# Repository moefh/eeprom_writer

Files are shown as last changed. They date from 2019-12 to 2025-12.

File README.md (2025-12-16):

# EEPROM Writer

A simple 28C16 EEPROM writer for Arduino Nano or Uno based on Ben Eater's [EEPROM programmer](https://github.com/beneater/eeprom-programmer).

This project includes:
- An arduino project that accepts commands from the serial USB to read or write the EEPROM
- A command line tool for Linux (might work on Mac?) written in C to read and write data files to the EEPROM

The circuit is heavily based on Ben Eater's [circuit](https://www.youtube.com/watch?v=K88pgWhEb1M) with a few changes to make it more robust when using an Arduino Uno. The main changes are:

- Don't use pin 13 for write enable (which is used by the Arduino during boot to blink the builtin LED). Instead we use the digital output of analog pins A0 to A2 to control the EEPROM chip enable, write enable and output enable pins.
- Add 10k resistors to pull down the shift register inputs do they don't float wildly while the Arduino is starting
- Add 10k resistors to pull up the enable pins of the EEPROM (chip enable, write enable and output enable) to make it more reliable (especially when arduino is starting up). 

## Circuit

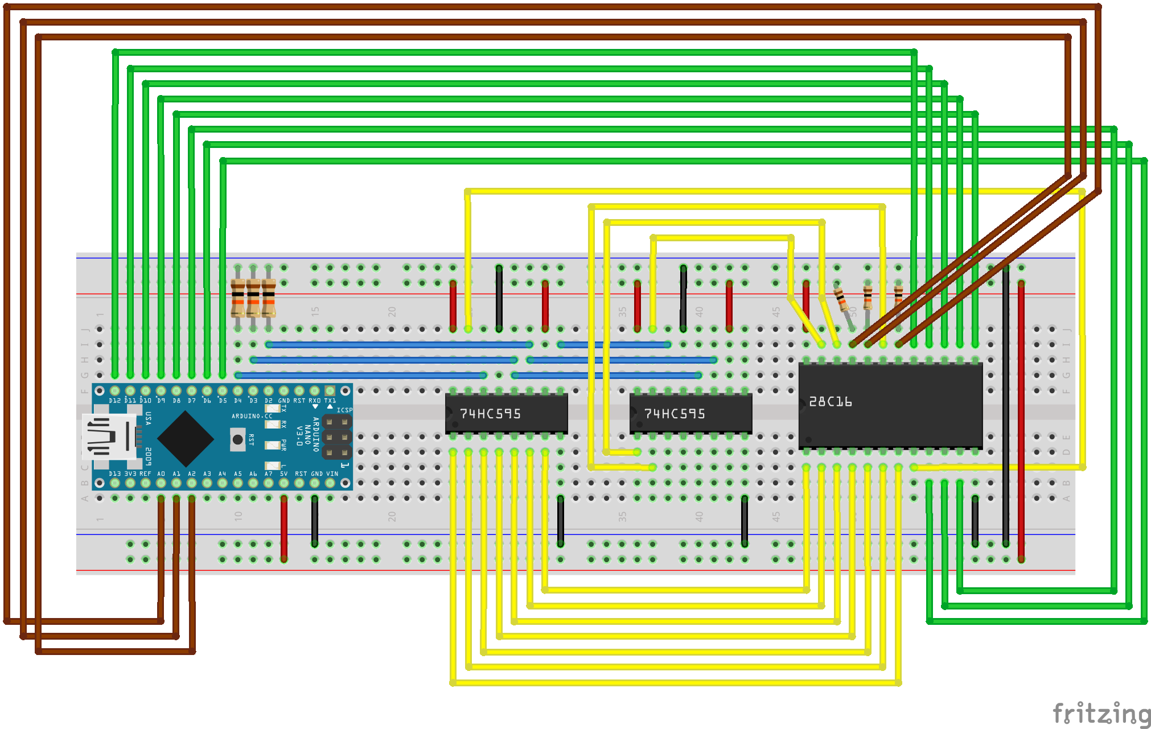
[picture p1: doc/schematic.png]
Schematic


NOTE: the image above shows wrong conections between Arduino pins D2-D4 and the left 74HC595. The correct connections are:

| Arduino | 74HC595 |
| --- | --- |
| D2 | 14 (SER) |
| D3 | 11 (SRCLK) |
| D4 | 12 (RCLK)  |

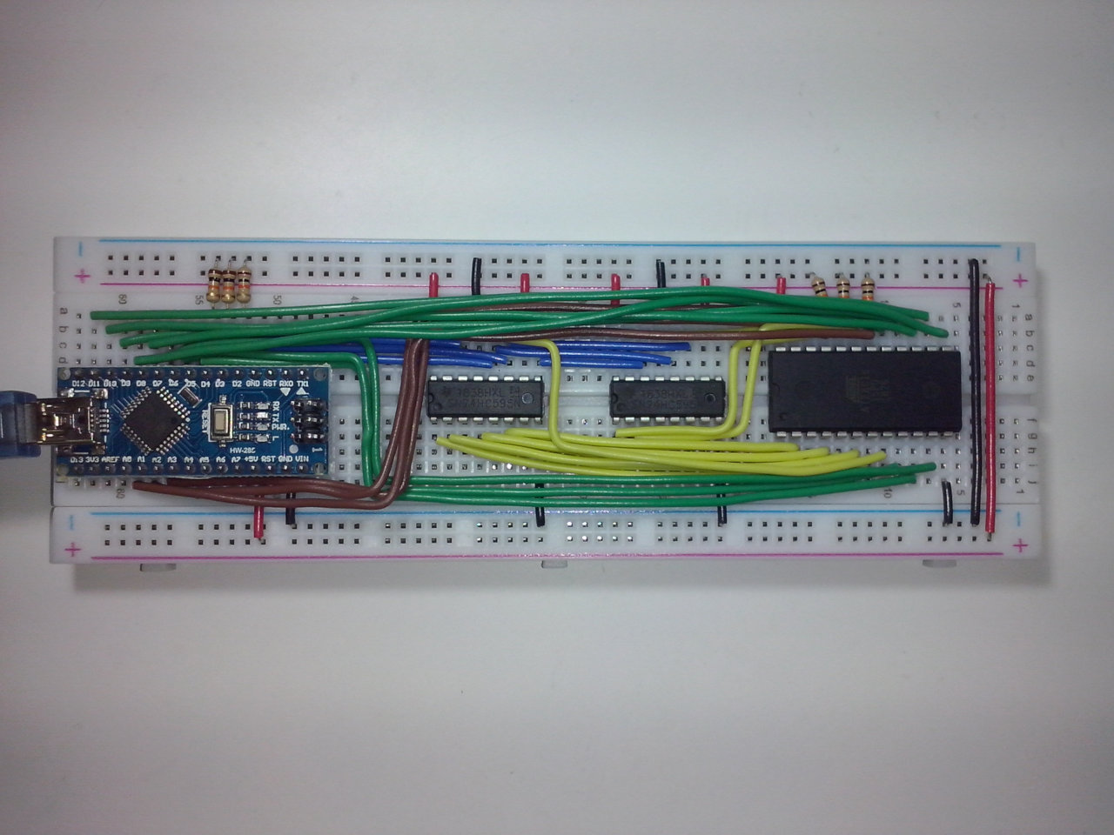
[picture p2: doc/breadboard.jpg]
Breadboard Photo


## Command Line Tool

The command line tool is written in C. To build it, just enter the `cmdline` directory and type `make` (make sure you have the necessary stuff installed, like `build-essential` if using Ubuntu).

The available commands are:

#### Show EEPROM contents

    eeprom dump [ADDRESS [LENGTH]]

Sends the contents of the EEPROM to the standard output formatted as traditional hexdump output. The default `ADDRESS` is `0` and the default `LENGTH` to the end of the EEPROM.  Examples:

    ./eeprom dump              # the whole EEPROM
    ./eeprom dump 0 64         # 64 bytes starting at address 0
    ./eeprom dump 0x200 0x80   # 128 bytes (0x80) starting at address 512 (0x200)

#### Read EEPROM contents to file

    eeprom read FILE [ADDRESS [LENGTH]]

Reads the contents of the EEPROM and writes the data to a file.  The default `ADDRESS` is `0` and the default `LENGTH` is the length of the EEPROM.  Examples:

    ./eeprom read file.bin           # the whole EEPROM
    ./eeprom read file.bin 0 64      # the first 64 bytes
    ./eeprom read file.bin 100 0x20  # 32 bytes (0x20) starting at address 100

#### Write file to EEPROM

    eeprom write FILE [ADDRESS]

Writes the whole contents of a file to the EEPROM.  The default `ADDRESS` is 0.  Examples:

    ./eeprom write file.bin          # writes to start of the EEPROM
    ./eeprom write file.bin 0x400    # writes to the address 1024 (0x400)

## Arduino Project

The Arduino program (found in `arduino/eeprom_writer`) waits for commands from the serial and executes them. The prompt

    *READY

is written to the serial port at the start and after every command is executed successfully. If a command fails, the prompt

    *ERROR: <message>

is written to the serial port.

The available commands are:

#### Dump

    d ADDRESS LENGTH

Reads data from `ADDRESS` to `ADDRESS+LENGTH` and sends it to the serial it in a classic "hexdump" format. Both numbers must be in hexadecimal.

#### Read

    r ADDRESS LENGTH

Reads data from `ADDRESS` to `ADDRESS+LENGTH` and sends it to the serial it in a stream of hex digits with no formatting. Both numbers must be in hexadecimal.

#### Write

    w ADDRESS LENGTH

Reads `LENGTH` pairs of hex digits (each pair representing a byte) from the serial and writes the bytes to the EEPROM starting at address `ADDRESS`. Both numbers must be in hexadecimal. I the data is not sent in 5 seconds, a timeout error is written to the serial and no data is written.

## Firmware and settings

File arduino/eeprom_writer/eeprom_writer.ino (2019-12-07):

// -*- c++ -*-

#define SHIFT_DATA       2
#define SHIFT_CLOCK      3
#define SHIFT_LATCH      4
#define EEPROM_D0        5
#define EEPROM_D7        12

#define EEPROM_CHIP_EN   14
#define EEPROM_OUT_EN    15
#define EEPROM_WR_EN     16

#define EEPROM_WRITE_TIMEOUT_MS 15    // timeout for EEPROM write (ms)
#define SERIAL_READ_TIMEOUT_MS  5000  // timeout for serial read of write buffer (ms)

unsigned char write_buf[512];

char tmp_buf[80];
unsigned int tmp_buf_size;

char cmd_buf[32];
unsigned int cmd_buf_size;
unsigned int cmd_buf_pos;
bool cmd_error_flag;

void setup()
{
  pinMode(LED_BUILTIN, OUTPUT);
  
  eeprom_init();
  
  Serial.begin(115200);
  Serial.println("\n*READY");
}

void loop()
{
  process_serial();
}

// ==============================================================================
// === Serial interface =========================================================
// ==============================================================================

void process_serial()
{
  while (Serial.available() > 0) {
    int b = Serial.read();
    if (b < 0) break;
    cmd_buf[cmd_buf_size++] = b;

    if (cmd_buf_size > 0 && cmd_buf[cmd_buf_size-1] == '\n') {
      cmd_buf_size--;
      process_cmd();
      cmd_buf_size = 0;
    } else if (cmd_buf_size >= (unsigned int) sizeof(cmd_buf)) {
      process_cmd();
      cmd_buf_size = 0;
    }
  }
}

void process_cmd()
{
  if (cmd_buf_size == 0) {
    return;
  }

  cmd_error_flag = false;
  cmd_buf_pos = 1;
  switch (cmd_buf[0]) {
  case 'r': process_read_cmd();    break;
  case 'w': process_write_cmd();   break;
  case 'd': process_dump_cmd();    break;
  default:  process_invalid_cmd(); break;
  }

  if (! cmd_error_flag) {
    Serial.println("\n*READY");
  }
}

void cmd_error(const char *msg)
{
  Serial.print("*ERROR: ");
  Serial.println(msg);
  cmd_error_flag = true;
}

int hex_to_nibble(char ch)
{
  if (ch >= '0' && ch <= '9') return ch - '0';
  if (ch >= 'a' && ch <= 'f') return ch - 'a' + 10;
  if (ch >= 'A' && ch <= 'F') return ch - 'A' + 10;
  return -1;
}

char nibble_to_hex(unsigned int nibble)
{
  if (nibble < 10) {
    return nibble + '0';
  }
  return nibble - 10 + 'a';
}

void write_char(char c)
{
  tmp_buf[tmp_buf_size++] = c;
}

void write_hex_u8(byte b)
{
  tmp_buf[tmp_buf_size++] = nibble_to_hex(b >> 4);
  tmp_buf[tmp_buf_size++] = nibble_to_hex(b & 0x0f);
}

void write_hex_u16(unsigned int b)
{
  tmp_buf[tmp_buf_size++] = nibble_to_hex((b >> 12) & 0x0f);
  tmp_buf[tmp_buf_size++] = nibble_to_hex((b >>  8) & 0x0f);
  tmp_buf[tmp_buf_size++] = nibble_to_hex((b >>  4) & 0x0f);
  tmp_buf[tmp_buf_size++] = nibble_to_hex((b >>  0) & 0x0f);
}

unsigned int read_hex()
{
  while (cmd_buf_pos < cmd_buf_size && cmd_buf[cmd_buf_pos] == ' ') {
    cmd_buf_pos++;
  }
  unsigned int start_pos = cmd_buf_pos;

  unsigned int num = 0;
  while (cmd_buf_pos < cmd_buf_size) {
    int nibble = hex_to_nibble(cmd_buf[cmd_buf_pos]);
    if (nibble < 0) {
      break;
    }
    num = (num << 4) | nibble;
    cmd_buf_pos++;
  }

  if (start_pos == cmd_buf_pos) {
    cmd_error("expected number");
  }
  return num;
}

// --- INVALID
void process_invalid_cmd()
{
  tmp_buf_size = 0;
  write_hex_u8(cmd_buf[0]);
  Serial.print("invalid command byte: ");
  Serial.println(tmp_buf);
  cmd_error("invalid command");
}

// --- READ
void process_read_cmd()
{
  unsigned int addr = read_hex();
  if (cmd_error_flag) return;
  unsigned int len = read_hex();
  if (cmd_error_flag) return;

  tmp_buf_size = 0;
  while (len-- > 0) {
    if (tmp_buf_size+2 >= (unsigned int) sizeof(tmp_buf)) {
      write_char('\0');
      Serial.println(tmp_buf);
      tmp_buf_size = 0;
    }
    byte b = read_eeprom_byte(addr++);
    write_hex_u8(b);
  }
  if (tmp_buf_size > 0) {
    write_char('\0');
    Serial.println(tmp_buf);
  }
}

// --- DUMP
void process_dump_cmd()
{
  unsigned int addr = read_hex();
  if (cmd_error_flag) return;
  unsigned int len = read_hex();
  if (cmd_error_flag) return;

  unsigned int end = addr + len;
  while (addr != end) {
    unsigned int line_len = end - addr;
    if (line_len > 16) line_len = 16;
    for (unsigned int i = 0; i < line_len; i++) {
      cmd_buf[i] = read_eeprom_byte(addr+i);
    }
    dump_line(cmd_buf, line_len, addr);
    addr += line_len;
  }
}

void dump_line(char *d, unsigned int len, unsigned int addr)
{
  tmp_buf_size = 0;
  
  write_hex_u16(addr);
  write_char(':');
  write_char(' ');
  for (unsigned int i = 0; i < len; i++) {
    write_char(' ');
    write_hex_u8(d[i]);
  }
  for (unsigned int i = len; i < 16; i++) {
    write_char(' ');
    write_char(' ');
    write_char(' ');
  }
  write_char(' ');
  write_char(' ');
  for (unsigned int i = 0; i < len; i++) {
    write_char((d[i] >= 0x20 && d[i] < 0x7f) ? d[i] : '.');
  }
  write_char('\0');
  Serial.println(tmp_buf);
}

// --- WRITE
void process_write_cmd()
{
  unsigned int addr = read_hex();
  if (cmd_error_flag) return;
  unsigned int len = read_hex();
  if (cmd_error_flag) return;

  if (len == 0 || len > (unsigned int) sizeof(write_buf)) {
    cmd_error("invalid length");
    Serial.print("len: ");
    Serial.println(len);
    return;
  }
  
  // read data from serial
  unsigned int write_buf_len = 0;
  unsigned long start_time = millis();
  unsigned long timeout_time = start_time + SERIAL_READ_TIMEOUT_MS;
  int high_nibble = -1;
  while (write_buf_len < len) {
    if (millis() > timeout_time) {
      cmd_error("read timeout");
      return;
    }

    while (Serial.available() > 0 && write_buf_len < len) {
      int c = Serial.read();
      if (c >= 0) {
        int nibble = hex_to_nibble(c);
        if (nibble < 0) {
          cmd_error("invalid data");
          return;
        }
        if (high_nibble < 0) {
          high_nibble = nibble << 4;
        } else {
          write_buf[write_buf_len++] = high_nibble | nibble;
          high_nibble = -1;
        }
      }
    }
    if (write_buf_len < len) {
      delay(1);
    }
  }

  // write data to EEPROM
  digitalWrite(LED_BUILTIN, HIGH);
  for (unsigned int i = 0; i < write_buf_len; i++) {
    write_eeprom_byte(addr + i, write_buf[i]);
  }
  digitalWrite(LED_BUILTIN, LOW);

  /*
  Serial.println("dump buffer:");
  for (unsigned int dump_pos = 0; dump_pos < write_buf_len; dump_pos += 16) {
    unsigned int line_len = write_buf_len - dump_pos;
    if (line_len > 16) line_len = 16;
    dump_line((char *)write_buf + dump_pos, line_len, addr + dump_pos);
  }
  */
}

// ==============================================================================
// === EEPROM interface =========================================================
// ==============================================================================

void eeprom_init()
{
  pinMode(SHIFT_DATA,  OUTPUT);
  pinMode(SHIFT_CLOCK, OUTPUT);
  pinMode(SHIFT_LATCH, OUTPUT);

  digitalWrite(EEPROM_WR_EN,  HIGH);
  digitalWrite(EEPROM_OUT_EN, HIGH);
  pinMode(EEPROM_OUT_EN,      OUTPUT);
  pinMode(EEPROM_WR_EN,       OUTPUT);
  pinMode(EEPROM_CHIP_EN,     OUTPUT);
}

void set_eeprom_address(unsigned int address)
{
  // shift data intp shift registers
  shiftOut(SHIFT_DATA, SHIFT_CLOCK, MSBFIRST, (address >> 8) & 0xff);
  shiftOut(SHIFT_DATA, SHIFT_CLOCK, MSBFIRST, (address >> 0) & 0xff);

  // latch value into shift registers' output
  digitalWrite(SHIFT_LATCH, LOW);
  delayMicroseconds(1);
  digitalWrite(SHIFT_LATCH, HIGH);
  delayMicroseconds(1);
  digitalWrite(SHIFT_LATCH, LOW);
}

byte read_eeprom_byte(unsigned int address)
{
  // set EEPROM address
  set_eeprom_address(address);

  // enable EEPROM data output
  for (int pin = EEPROM_D0; pin <= EEPROM_D7; pin++) {
    pinMode(pin, INPUT);
  }
  digitalWrite(EEPROM_OUT_EN, LOW);
  
  // read EEPROM data
  byte data = 0;
  for (int pin = EEPROM_D7; pin >= EEPROM_D0; pin--) {
    data = (data<<1) | (digitalRead(pin) ? 1 : 0);
  }
  return data;
}

void write_eeprom_byte(unsigned int address, byte data)
{
  // disable EEPROM data output
  digitalWrite(EEPROM_OUT_EN, HIGH);

  // setup EEPROM address and data
  set_eeprom_address(address);
  for (int pin = EEPROM_D0; pin <= EEPROM_D7; pin++) {
    pinMode(pin, OUTPUT);
  }
  for (int pin = EEPROM_D0; pin <= EEPROM_D7; pin++) {
    digitalWrite(pin, data & 1);
    data >>= 1;
  }

  // pulse EEPROM write enable pin
  noInterrupts();
  digitalWrite(EEPROM_WR_EN, LOW);
  delayMicroseconds(1);
  digitalWrite(EEPROM_WR_EN, HIGH);
  interrupts();

  // enable EEPROM data output
  digitalWrite(EEPROM_OUT_EN, LOW);
  
  // wait for EEPROM data to match written data
  byte got_data = 0;
  long start_time = millis();
  long cur_time = start_time;
  long max_time = cur_time + EEPROM_WRITE_TIMEOUT_MS;
  do {
    delay(1);
    for (int pin = EEPROM_D7; pin >= EEPROM_D0; pin--) {
      got_data = (got_data<<1) | (digitalRead(pin) ? 1 : 0);
    }
    cur_time = millis();
  } while (got_data != data && cur_time < max_time);

  // disable EEPROM output
  digitalWrite(EEPROM_OUT_EN, HIGH);

  //Serial.print("waited for ");
  //Serial.print(cur_time - max_time);
  //Serial.println("ms");
}

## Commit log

2019-12-07 Added command line tool and arduino code
2019-12-07 Add Fritzing schematic
    [eeprom_writer.fzz]
2019-12-07 Replace schematic image
2025-12-16 Add a note about wrong pin connections in the diagram
